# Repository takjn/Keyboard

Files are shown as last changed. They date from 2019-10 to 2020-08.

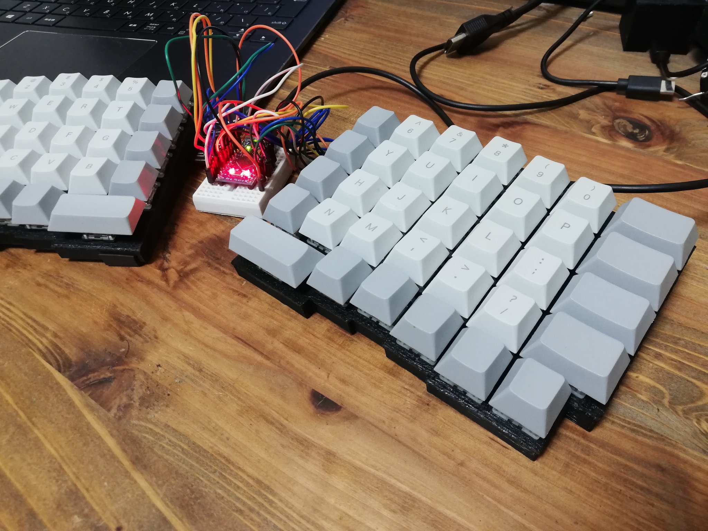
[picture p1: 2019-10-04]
photo.jpg

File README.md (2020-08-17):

# DIY 3D printed keyboard
## Layout
Build from scratch with 3D printer.
- 66% keyboard (68 keys, 6 row x 12 col)
- 3D printed, split, column Staggered layout

## Firmware
There are three versions.
- Bluetooth HID keyboard with tinygo using ATmega328P and RN42HID
- USB HID keyboard with micropython using GR-CITRUS
- USB HID keyboard with Arduino using pro micro

## Reference
- https://github.com/ktcode/ktKEYBOARD
- http://eucalyn.hatenadiary.jp/entry/original-keyboard-08

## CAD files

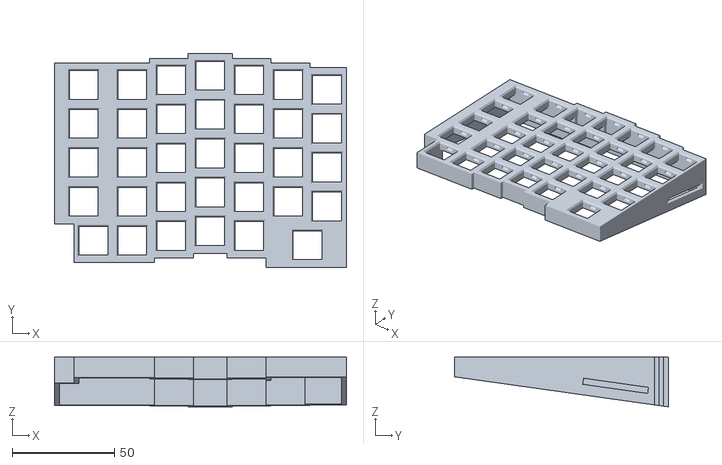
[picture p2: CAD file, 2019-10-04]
keyboard_left.stl
142.5 x 104.3 x 24.3

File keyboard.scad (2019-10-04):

 
key_pitch_x = 19;
key_pitch_y = 19;
hole_x = 14;
hole_y = 14;
panel_thick = 5;

front_height = 18;
angle = 8;

gap1 = 0.01;
gap2 = gap1 * 2;

// Type-a
//mirror([1,0,0]) {
translate( [0, 0, 0] ){
    // length of side function keys
    ctl_key_width = 1.5;
    row0_x = ctl_key_width - 1;

    difference(){
        union(){
            // left side control keys
            for( y = [1:4] ) key( 0, y, ctl_key_width);

            // alphanumeric keys
            union(){
                for( y = [1:4] ) key( ctl_key_width + 0, y + 0 * 0.12);
                for( y = [1:4] ) key( ctl_key_width + 1, y + 1 * 0.12);
                for( y = [1:4] ) key( ctl_key_width + 2, y + 2 * 0.12);
                for( y = [1:4] ) key( ctl_key_width + 3, y + 1 * 0.12);
                for( y = [1:4] ) key( ctl_key_width + 4, y + 0 * 0.12);
            }
            
            // right side control keys
            for( y = [1:4] ) key(ctl_key_width + 5 , y-0.12);

            // bottom control keys
            key( row0_x + 0, 0 );
            key( row0_x + 1, 0 );
            key( row0_x + 2, 0 + 0.12);
            key( row0_x + 3, 0 + 0.24);
            key( row0_x + 4, 0 + 0.12);

            // space key
            fill( row0_x + 5 + 0  , -0.12, 0.5 );
            key ( row0_x + 5 + 0.5, -0.12, 1.0 );
            fill( row0_x + 5 + 1.5, -0.12, 0.5 );
            fill( row0_x + 5, 1-0.12, 1, 0.12);

            // outline
            difference(){
                // wall
                union(){
                    // upper edge
                    wall_x_left( 0, 2.5, 5);
                    wall_x( 2.5, 3.5, 5 + 0.12 );
                    wall_x( 3.5, 4.5, 5 + 0.24 );
                    wall_x( 4.5, 5.5, 5 + 0.12 );
                    wall_x( 5.5, 6.5, 5);
                    wall_x_right( 6.5, 7.5, 5 - 0.12 );

                    // bottom edge
                    wall_x_left( 0.0, 0.5, 1);
                    wall_x_left( 0.5, 2.5, 0);
                    wall_x( 2.5, 3.5, 0 + 0.12 );
                    wall_x( 3.5, 4.5, 0 + 0.24 );
                    wall_x( 4.5, 5.5, 0 + 0.12 );
                    wall_x_right( 5.5, 7.5, 0 - 0.12);

                    // left edge
                    wall_y_left( 0, 1, 5 );
                    wall_y_left( 0.5, 0, 1 );

                    // right edge
                    wall_y_right( 7.5, 0 - 0.12, 5 - 0.12 );
                    wall_y( 5.5, 0 - 0.12, 0.5 );
                }
                // cable hole
                translate( [key_pitch_x*7.5, key_pitch_y*3.95, -14] ){
                    rotate([-angle,0,0]) {
                        cube( [panel_thick, 32, 3], center=true );
                    }
                }
            }
        }
        
        rotate( a=-angle, v=[1, 0, 0] )
        translate( [-key_pitch_x*3, -key_pitch_y*5, -front_height-42] )
        cube( [key_pitch_x*13, key_pitch_y*13, 50] );
    }
}
//}

//// Type-b left
//translate( [-150, 0, 0] ){
//    difference(){
//        union(){
//            // left side control keys
//            key( 0,        4, 1);
//            key( 0,        3, 1);
//            key( 0 + 0.25, 2, 1);
//            key( 0 + 0.25, 1, 1.5);
//
//            // alphanumeric keys
//            union(){
//                for( x = [0:5] ) key( 1 + x,              4);
//                for( x = [0:5] ) key( 1 + x ,             3);
//                for( x = [0:5] ) key( 1 + x + 0.25,       2);
//                for( x = [0:5] ) key( 1 + x + 0.25 + 0.5, 1);
//            }
//            
//            // bottom control keys
//            row0_x=0.25+0.5+1;
//            key( row0_x - 0.5, 0, 1.5);
//            key( row0_x + 1  , 0);
//            key( row0_x + 2  , 0);
//            key( row0_x + 3  , 0);
//
//            // space key
//            fill( row0_x + 4 + 0  , 0, 0.5 );
//            key ( row0_x + 4 + 0.5, 0, 1.0 );
//            fill( row0_x + 4 + 1.5, 0, 0.5 );
//
//            // outline
//            difference(){
//                // wall
//                union(){
//                    // upper edge
//                    wall_x_left ( 0,      6,          5);
//                    wall_x_right( 6,      7,          5);
//                    wall_x_right( 7,      7,          4);
//                    wall_x_right( 7,      7+0.25,     3);
//                    wall_x_right( 7+0.25, 7+0.25+0.5, 2);
//
//                    // bottom edge
//                    wall_x_left ( 0.25 + 1, 7.5, 0);
//                    wall_x_right( 7.5, 7.5+0.25, 0);
//
//                    wall_x_left( 0     , 0     , 4);
//                    wall_x_left( 0     , 0.25  , 3);
//                    wall_x_left( 0+0.25, 0.25+1, 1);
//
//                    // left edge
//                    wall_y_left( 0     , 4, 5 );
//                    wall_y_left( 0     , 3, 4 );
//                    wall_y_left( 0.25  , 1, 3 );
//                    wall_y_left( 0.25+1, 0, 1 );
//
//                    // right edge
//                    wall_y_right( 7         , 4, 5);
//                    wall_y_right( 7         , 3, 4);
//                    wall_y_right( 7+0.25    , 2, 3);
//                    wall_y_right( 7+0.25+0.5, 0, 2);
//                }
//                // cable hole
//                translate( [key_pitch_x*7.5, key_pitch_y*3.95, -14] ){
//                    rotate([-angle,0,0]) {
//                        cube( [50, 32, 3], center=true );
//                    }
//                }
//            }
//        }
//        
//        rotate( a=-angle, v=[1, 0, 0] )
//        translate( [-key_pitch_x*3, -key_pitch_y*5, -front_height-42] )
//        cube( [key_pitch_x*13, key_pitch_y*13, 50] );
//    }
//}
//
//// Type-b right
//translate( [15, 0, 0] ){
//    difference(){
//        union(){
//            // right side control keys
//            key( 5.5-0.25, 4, 1.5);
//            key( 5.5-0.25, 3, 1.5);
//            key( 5.5,      2, 1.5);
//            key( 6,        1, 1.0);
//
//            // alphanumeric keys
//            union(){
//                for( x = [0:5] ) key( x - 0.5 - 0.25, 4);
//                for( x = [0:5] ) key( x - 0.5 - 0.25, 3);
//                for( x = [0:5] ) key( x - 0.5,        2);
//                for( x = [0:5] ) key( x,              1);
//            }
//            
//            // space key
//            fill( 0  , 0, 0.5 );
//            key ( 0.5, 0, 1.0 );
//            fill( 1.5, 0, 0.5 );
//            key ( 2.0, 0 );
//
//            // cursol keys
//            key( 3.0 + 2, 0 );
//            key( 3.0 + 1, -1);
//            key( 3.0 + 2, -1);
//            key( 3.0 + 3, -1);
//
//            // outline
//            difference(){
//                // wall
//                union(){
//                    // upper edge
//                    wall_x_left ( 0-0.5-0.25, 3, 5);
//                    wall_x_right( 3, 5.5+1.5-0.25, 5);
//
//                    wall_x_right( 5.5+1.5-0.25, 5.5+1.5, 3);
//
//                    wall_x_left ( 4, 5, 0);
//                    wall_x_right( 6, 7, 0);
//
//                    // bottom edge
//                    wall_x_left ( -0.5-0.25, -0.5, 3);
//                    wall_x_left ( -0.5, 0, 2);
//
//                    wall_x_left ( 0, 1.5, 0);
//                    wall_x_right( 1.5, 3, 0);
//
//                    wall_x_left ( 3, 4, 1);
//                    wall_x_right( 4, 5, 1);
//
//                    wall_x_left ( 6, 6.5, 1);
//                    wall_x_right( 6.5, 7, 1);
//
//                    wall_x_left ( 4, 5.5, -1);
//                    wall_x_right( 5.5, 7, -1);
//
//
//                    // left edge
//                    wall_y_left( 0-0.5-0.25, 3, 5);
//                    wall_y_left( 0-0.5,      2, 3);
//                    wall_y_left( 0,          0, 2);
//
//                    wall_y_left( 4.5+0.50,  0, 1);
//                    wall_y_left( 3.5+0.50,  -1, 0);
//
//
//                    // right edge
//                    wall_y_right( 6.5+0.25,  3, 5);
//                    wall_y_right( 6.5+0.50,  1, 3);
//                    wall_y_right( 5.5+0.50,  0, 1);
//                    wall_y_right( 6.5+0.50,  -1, 0);
//                    wall_y_right( 2.5+0.50,  0, 1);
//                }
//                // cable hole
//                translate( [key_pitch_x*-0.5, key_pitch_y*3.95, -14] ){
//                    rotate([-angle,0,0]) {
//                        cube( [50, 32, 3], center=true );
//                    }
//                }
//            }
//        }
//        
//        rotate( a=-angle, v=[1, 0, 0] )
//        translate( [-key_pitch_x*3, -key_pitch_y*5, -front_height-42] )
//        cube( [key_pitch_x*13, key_pitch_y*13, 50] );
//    }
//}
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

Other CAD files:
keyboard_right.stl

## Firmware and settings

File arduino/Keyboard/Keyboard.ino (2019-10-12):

// Based on
// http://eucalyn.hatenadiary.jp/entry/original-keyboard-08
#include "Keyboard.h"

const int rowNum = 6;
const int colNum = 12;

const int rowPin[rowNum] = {  1, 0, 2, 3, 4, 5 };
const int colPin[colNum] = { 10, 16, 9, 8, 7, 6, 21, 20, 19, 18, 15, 14 };

// Key map definition
// https://www.arduino.cc/reference/en/language/functions/usb/keyboard/keyboardmodifiers/
// http://www.asciitable.com/
// NOTE: use 0x00 for layer switch

const byte keyMap1[rowNum][colNum] = {
  { 0x00,           0x00, 0x27, 0x5B, 0x2D, 0x60                         ,0x5C, 0x3D, 0x5D, 0x2F, 0x00, 0x00},
  { KEY_ESC,        0x31, 0x32, 0x33, 0x34, 0x35                         ,0x36, 0x37, 0x38, 0x39, 0x30, KEY_DELETE},
  { KEY_TAB,        0x71, 0x77, 0x65, 0x72, 0x74                         ,0x79, 0x75, 0x69, 0x6F, 0x70, KEY_BACKSPACE},
  { KEY_LEFT_CTRL,  0x61, 0x73, 0x64, 0x66, 0x67                         ,0x68, 0x6A, 0x6B, 0x6C, 0x3B, KEY_RETURN},
  { KEY_LEFT_SHIFT, 0x7A, 0x78, 0x63, 0x76, 0x62                         ,0x6E, 0x6D, 0x2C, 0x2E, KEY_UP_ARROW, KEY_RIGHT_SHIFT},
  { KEY_LEFT_CTRL, KEY_LEFT_CTRL, KEY_LEFT_GUI, KEY_LEFT_ALT, 0x00, 0x20 ,0x20, 0x00, KEY_RIGHT_ALT, KEY_LEFT_ARROW, KEY_DOWN_ARROW, KEY_RIGHT_ARROW}
};

const byte keyMap2[rowNum][colNum] = {
  { 0x00,           0x00, 0x22, 0x7B, 0x5F, 0x7E                                               ,0x7C, 0x2B, 0x7D, 0x2F, 0x00, 0x00},
  { KEY_ESC,        KEY_F1, KEY_F2, KEY_F3, KEY_F4, KEY_F5                                     ,KEY_F6, KEY_F7, KEY_F8, KEY_F9, KEY_F10, KEY_INSERT},
  { KEY_TAB,        KEY_HOME, KEY_UP_ARROW, KEY_END, KEY_PAGE_UP, 0x74                         ,KEY_HOME, KEY_UP_ARROW, KEY_END, KEY_PAGE_UP, 0x70, KEY_BACKSPACE},
  { KEY_LEFT_CTRL,  KEY_LEFT_ARROW, KEY_DOWN_ARROW, KEY_RIGHT_ARROW, KEY_PAGE_DOWN, 0x67       ,KEY_LEFT_ARROW, KEY_DOWN_ARROW, KEY_RIGHT_ARROW, KEY_PAGE_DOWN, 0x3B, KEY_RETURN},
  { KEY_LEFT_SHIFT, 0x7A, 0x78, 0x63, 0x76, 0x62                                               ,0x6E, 0x6D, 0x2C, 0x2E, KEY_PAGE_UP, KEY_RIGHT_SHIFT},
  { KEY_LEFT_CTRL, KEY_LEFT_CTRL, KEY_LEFT_GUI, KEY_LEFT_ALT, 0x00, 0x20                       ,0x20, 0x00, KEY_RIGHT_ALT, KEY_HOME, KEY_PAGE_DOWN, KEY_END}
};

byte *keyMap;

bool currentState[rowNum][colNum];
bool beforeState[rowNum][colNum];

int i,j;

void setup() {
  keyMap = *keyMap1;
  
  for( i = 0; i < rowNum; i++){
    pinMode(rowPin[i],OUTPUT);
  }

  for( i = 0; i < colNum; i++){
    pinMode(colPin[i],INPUT_PULLUP);
  }

  for( i = 0; i < rowNum; i++){
    for( j = 0; j < colNum; j++){
      currentState[i][j] = HIGH;
      beforeState[i][j] = HIGH;
    }
    digitalWrite(rowPin[i],HIGH);
  }

  Serial.begin(9600);
  Keyboard.begin();
}

void loop() {
  delay(5);
  
  for( i = 0; i < rowNum; i++){
    digitalWrite( rowPin[i], LOW );

    for( j = 0; j < colNum; j++){
      currentState[i][j] = digitalRead(colPin[j]);

      if ( currentState[i][j] != beforeState[i][j] ){

        Serial.print("key(");
        Serial.print(i);
        Serial.print(",");
        Serial.print(j);
        Serial.print(")");

        if ( currentState[i][j] == LOW){
          Serial.println(" Push!");
          Keyboard.press( keyMap[i*colNum+j] );

          // layer switch
          if (keyMap[i*colNum+j] == 0x00) {
            keyMap = *keyMap2;
          }
        } else {
          Serial.println(" Release!");
          Keyboard.release( keyMap[i*colNum+j] );

          //layer switch
          if (keyMap[i*colNum+j] == 0x00) {
            keyMap = *keyMap1;
          }
        }
      beforeState[i][j] = currentState[i][j];
      }
    }
    digitalWrite( rowPin[i], HIGH );
  }
}

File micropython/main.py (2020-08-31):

from machine import Pin
from machine import UART
from key import Key
# from rn42 import RN42
from usb import USB


class Keyboard:
    cols = ['PIN10', 'PIN11', 'PIN9', 'PIN8', 'PIN7', 'PIN4', 'PIN17', 'PIN16', 'PIN15', 'PIN14', 'PIN13', 'PIN12']
    rows = ['PIN18', 'PIN19', 'PIN2', 'PIN3', 'PIN5', 'PIN6']
    key_map = [
        [
            [Key.NONE, Key.NONE, Key.APOSTROPHE, Key.LEFTBRACE, Key.MINUS, Key.GRAVE, Key.BACKSLASH, Key.EQUAL, Key.RIGHTBRACE, Key.SLASH, Key.NONE, Key.NONE],
            [Key.ESC, Key.K1, Key.K2, Key.K3, Key.K4, Key.K5, Key.K6, Key.K7, Key.K8, Key.K9, Key.K0, Key.DELETE],
            [Key.TAB, Key.Q, Key.W, Key.E, Key.R, Key.T, Key.Y, Key.U, Key.I, Key.O, Key.P, Key.BACKSPACE],
            [Key.LEFTCTRL, Key.A, Key.S, Key.D, Key.F, Key.G, Key.H, Key.J, Key.K, Key.L, Key.SEMICOLON, Key.ENTER],
            [Key.LEFTSHIFT, Key.Z, Key.X, Key.C, Key.V, Key.B, Key.N, Key.M, Key.COMMA, Key.DOT, Key.UP, Key.RIGHTSHIFT],
            [Key.LEFTCTRL, Key.SYSRQ, Key.LEFTMETA, Key.LEFTALT, Key.NONE, Key.SPACE, Key.SPACE, Key.NONE, Key.COMPOSE, Key.LEFT, Key.DOWN, Key.RIGHT],
        ],
        [
            [Key.NONE, Key.NONE, Key.APOSTROPHE, Key.LEFTBRACE, Key.MINUS, Key.GRAVE, Key.BACKSLASH, Key.EQUAL, Key.RIGHTBRACE, Key.SLASH, Key.NONE, Key.NONE],
            [Key.ESC, Key.F1, Key.F2, Key.F3, Key.F4, Key.F5, Key.F6, Key.F7, Key.F8, Key.F9, Key.F10, Key.DELETE],
            [Key.TAB, Key.Q, Key.W, Key.E, Key.R, Key.T, Key.Y, Key.U, Key.I, Key.F11, Key.F12, Key.BACKSPACE],
            [Key.LEFTCTRL, Key.A, Key.S, Key.D, Key.F, Key.G, Key.H, Key.J, Key.K, Key.L, Key.SEMICOLON, Key.ENTER],
            [Key.LEFTSHIFT, Key.Z, Key.X, Key.C, Key.V, Key.B, Key.N, Key.M, Key.COMMA, Key.DOT, Key.PAGEUP, Key.RIGHTSHIFT],
            [Key.LEFTCTRL, Key.SYSRQ, Key.LEFTMETA, Key.LEFTALT, Key.NONE, Key.SPACE, Key.SPACE, Key.NONE, Key.COMPOSE, Key.HOME, Key.PAGEDOWN, Key.END],
        ]
    ]

    # layer holds the current key map layer (0 or 1)
    layer = 0

    def __init__(self):
        # Set up pins
        for row in self.rows:
            r = Pin(row, Pin.OUT)
            r.on()

        for col in self.cols:
            _ = Pin(col, Pin.IN, Pin.PULL_UP)

        # workaround for MicroPython v1.9.4-1354-gebbaac271-dirty on 2019-11-24; GR-CITRUS with RX631
        for row in ['PIN5_A', 'PIN6_A']:
            r = Pin(row, Pin.OUT)
            r.on()

    def read_matrix(self):
        scan_codes = bytearray(b'\x00\x00\x00\x00\x00\x00')
        scan_code_length = len(scan_codes)
        idx = 0
        modifier = 0
        layer_switch = False

        for i, row in enumerate(self.rows):
            r = Pin(row, Pin.OUT)
            r.off()

            # workaround for MicroPython v1.9.4-1354-gebbaac271-dirty on 2019-11-24; GR-CITRUS with RX631
            if (row == 'PIN5'):
                p = Pin('PIN5_A', Pin.OUT)
                p.off()
            if (row == 'PIN6'):
                p = Pin('PIN6_A', Pin.OUT)
                p.off()

            for j, col in enumerate(self.cols):
                c = Pin(col, Pin.IN, Pin.PULL_UP)

                # A pin is pulled up (set high) by default.
                # It should be false (low) when the key is pressed.
                if c.value() == 1:
                    continue

                # Get the scan code
                scan_code = self.key_map[self.layer][i][j]

                # Check layer key is pressed
                if scan_code == Key.NONE:
                    layer_switch = True

                # Check modifier key is pressed
                if scan_code >= 0xe0 and scan_code <= 0xe7:
                    shift = scan_code & 0b111
                    mask = 1 << shift
                    modifier = modifier | mask

                # Set the scan code
                if idx < scan_code_length:
                    scan_codes[idx] = scan_code
                    idx += 1
                else:
                    for k, _ in enumerate(scan_codes):
                        scan_codes[k] = Key.ERROVF

                # print("row: {}, col: {}".format(i, j))
            r.on()

            # workaround for MicroPython v1.9.4-1354-gebbaac271-dirty on 2019-11-24; GR-CITRUS with RX631
            if (row == 'PIN5'):
                p = Pin('PIN5_A', Pin.OUT)
                p.on()
            if (row == 'PIN6'):
                p = Pin('PIN6_A', Pin.OUT)
                p.on()

        # Set layer
        if layer_switch:
            self.layer = 1
        else:
            self.layer = 0

        return scan_codes, modifier


def main():
    # uart = UART(0, 115200)
    # hid = RN42(uart)
    usb_hid = pyb.USB_HID()
    hid = USB(usb_hid)

    k = Keyboard()

    # last_scan_codes hold the last scan codes to detect key press and key release
    last_scan_codes = bytearray(b'\x00\x00\x00\x00\x00\x00')
    last_modifier = 0

    while 1:
        scan_codes, modifier = k.read_matrix()

        # Send scan codes if the scan codes is different from the last data.
        if last_scan_codes != scan_codes or last_modifier != modifier:
            hid.send_keyboard_report(scan_codes, modifier)
            last_scan_codes = scan_codes
            last_modifier = modifier
            # print(scan_codes, modifier)

        pyb.delay(1)


main()

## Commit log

2019-10-12 changed pin assign
2019-10-20 change: pin assingn
2019-12-02 fix: comment out delay
    [main.py]
